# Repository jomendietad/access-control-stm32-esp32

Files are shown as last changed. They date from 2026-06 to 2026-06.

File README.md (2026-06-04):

# Sistema de Control de Acceso Distribuido (STM32 + ESP32-S3)

Este repositorio contiene el código fuente para un **Sistema de Control de Acceso Distribuido**. El proyecto resuelve la necesidad de validar ingresos físicos mediante autenticación de doble factor (RFID local y Visión Artificial remota), dividiendo las responsabilidades computacionales y de control físico entre dos microcontroladores distintos.

Esta arquitectura de "doble nodo" permite aislar y proteger la interacción física en tiempo real, delegando las tareas de procesamiento intensivo, almacenamiento de datos y conectividad web a un nodo especializado.

---

## Filosofía de Diseño: Arquitectura de Nodos

El sistema abandona el paradigma monolítico clásico para operar bajo una topología de **Nodo de Borde (Edge Node)** y **Nodo Central (Core Node)**.

### 1. Nodo Físico / Edge Node (STM32)

Su prioridad absoluta es garantizar la seguridad física y proporcionar una respuesta determinista en tiempo real.

* **Responsabilidades:** Gestión del lector de tarjetas RFID (MFRC522), lectura del sensor de presencia volumétrica (PIR), control de la interfaz visual de usuario (OLED SSD1306) y accionamiento de potencia del relé de la cerradura electromecánica.
* **Estado de Hardware:** Implementado transitoriamente en una tarjeta de desarrollo **NUCLEO-L476RG**. La estructura del firmware está diseñada para garantizar una migración directa y transparente hacia la placa definitiva: una **PCB personalizada basada en el microcontrolador STM32F0**.

### 2. Nodo Central / Core Node (ESP32-S3)

Actúa como el motor computacional del sistema. Gestiona tareas asíncronas de alta carga que comprometerían el tiempo de respuesta del nodo STM32.

* **Responsabilidades:** Procesamiento de algoritmos de visión artificial, gestión de conectividad inalámbrica, alojamiento del servidor HTTP/WebSockets y registro persistente de eventos en memoria no volátil.
* **Nota sobre Retroalimentación Visual (LEDs):** Aunque la capa BSP del ESP32 incorpora el controlador para tiras LED direccionables WS2812 (`bsp_led`), **esta funcionalidad se encuentra inactiva en el flujo principal (`main`) y en la máquina de estados actual**. Las notificaciones visuales del sistema operan exclusivamente a través de la pantalla OLED del STM32.

---

## Diagrama de Bloques del Sistema

El siguiente diagrama ilustra la separación de recursos de hardware y el puente de comunicación asíncrona entre ambas arquitecturas:

```mermaid
graph TD
    %% --- NODO FISICO: STM32 ---
    subgraph STM32 ["EDGE NODE: STM32 (Control Físico)"]
        direction TB
        
        subgraph SwSTM ["Capa de Software (Firmware)"]
            M_STM["Capa Main<br><i>(main.c / App_Task)</i>"]
            A_STM["Capa App: FSM Local<br><i>(app_core.c)</i>"]
            B_STM["Capa BSP: Drivers Placa<br><i>(bsp_placa.h)</i>"]
            
            M_STM --> A_STM
            A_STM <--> B_STM
        end

        %% Periféricos Físicos
        RFID["Lector RFID<br><b>(MFRC522)</b>"]
        PIR["Sensor Presencia<br><b>(PIR)</b>"]
        RELE["Cerradura<br><b>(Relé Potencia)</b>"]
        OLED["Interfaz Usuario<br><b>(OLED SSD1306)</b>"]

        %% Conexiones de Hardware Internas
        B_STM <-->|Bus SPI| RFID
        PIR -->|GPIO Input| B_STM
        B_STM -->|GPIO Output| RELE
        B_STM -->|Bus I2C| OLED
    end

    %% --- NODO COMPUTACIONAL: ESP32-S3 ---
    subgraph ESP32 ["CORE NODE: ESP32-S3 (Procesamiento)"]
        direction TB
        
        subgraph SwESP ["Capa de Software (Infraestructura)"]
            M_ESP["Capa Main<br><i>(main.c)</i>"]
            A_ESP["Capa App: Visión/Lógica<br><i>(app_cv.c)</i>"]
            B_ESP["Capa BSP: Drivers Placa<br><i>(bsp_placa.h)</i>"]
            
            M_ESP --> A_ESP
            A_ESP <--> B_ESP
        end

        %% Periféricos / Conectividad
        RED(("Red Local / Web<br><b>(HTTP / WebSockets)</b>"))
        MEM["Memoria Flash<br><b>(NVS)</b>"]
        LED["Feedback Visual<br><b>(WS2812 RGB)</b>"]

        %% Conexiones de Hardware Internas
        B_ESP <-->|Wi-Fi / TCP-IP| RED
        B_ESP <-->|Bus Interno| MEM
        B_ESP -.->|Driver Inactivo| LED
    end

    %% --- BUS DE COMUNICACIÓN INTER-NODO ---
    B_STM <-->|Canal UART Asíncrono<br>RX / TX Directo| B_ESP

    %% --- ESTILOS VISUALES (Clases CSS para Escaneabilidad) ---
    classDef mainLayer fill:#e3f2fd,stroke:#1565c0,stroke-width:2px,color:#0d47a1;
    classDef appLayer fill:#fff3e0,stroke:#ef6c00,stroke-width:2px,color:#e65100;
    classDef bspLayer fill:#e8f5e9,stroke:#2e7d32,stroke-width:2px,color:#1b5e20;
    classDef hw fill:#f5f5f5,stroke:#424242,stroke-width:1px,color:#212121;
    classDef inactive fill:#fafafa,stroke:#b0bec5,stroke-width:1px,color:#90a4ae,stroke-dasharray: 5 5;

    %% Asignación de Estilos
    class M_STM,M_ESP mainLayer;
    class A_STM,A_ESP appLayer;
    class B_STM,B_ESP bspLayer;
    class RFID,PIR,RELE,OLED,RED,MEM hw;
    class LED inactive;

```

---

## Arquitectura de Software (Strict 3-Layer Architecture)

Para facilitar la inminente migración de hardware (de Nucleo a la PCB personalizada) sin necesidad de refactorizar la lógica central, **ambos microcontroladores** implementan de forma rigurosa una arquitectura de software de tres capas. La totalidad del código fuente está redactada en inglés.

1. **Capa BSP (Board Support Package):** Modularizada por componente físico (ej. `bsp_uart.c`, `bsp_rfid.c`). Es la **única capa autorizada** para interactuar con las bibliotecas del fabricante (HAL de STM32 o ESP-IDF) y manipular registros físicos. Todos los submódulos convergen en un archivo maestro `bsp_placa.h`.
2. **Capa App (Business Logic):** Modularizada por funcionalidad (ej. `app_core.c`, `app_cv.c`). Es completamente agnóstica al hardware; está **estrictamente prohibida** la inclusión de directivas de registros o manejo de periféricos a este nivel. Contiene las máquinas de estado y expone sus interfaces a través de `app.h`.
3. **Capa Main:** Diseñada con un enfoque minimalista. Únicamente incluye `app.h`, ejecuta la inicialización global (`App_Init()`) y mantiene un bucle infinito dedicado de forma exclusiva a la invocación de `App_Task()`.

---

## Flujo de Ejecución y Casos de Uso

El núcleo operativo del sistema reside en la Máquina de Estados Finitos (FSM) ejecutada en la capa de aplicación del STM32 (`app_core.c`). Este bucle principal (`App_Task`) opera de manera estrictamente asíncrona, evitando bloqueos por funciones de retardo.

### Estado Inicial: `STATE_IDLE`

Representa el estado de reposo y vigilancia. El relé permanece desenergizado (cerradura bloqueada). La pantalla OLED se limpia o muestra un mensaje de espera. En cada iteración del bucle, el STM32 ejecuta tres acciones:

1. Interroga el bus SPI para detectar la presencia de una tarjeta en el lector RFID.
2. Verifica si la rutina de interrupción UART ha señalado la recepción de un comando desde el ESP32.
3. Evalúa el estado lógico del pin asociado al sensor PIR.

A partir de este estado de vigilancia, pueden desencadenarse tres eventos principales:

### Caso 1: Ingreso Concedido por RFID (Validación Local)

1. El usuario aproxima un transpondedor RFID al lector.
2. La capa BSP extrae el UID de la tarjeta y lo transfiere a la capa App.
3. La capa App compara el UID contra la base de datos almacenada localmente.
4. **Al verificar una coincidencia**, la FSM transiciona a `STATE_ACCESS_GRANTED`.
5. Se comanda al BSP para energizar el relé y liberar la cerradura. El display OLED indica **"ACCESS GRANTED"**.
6. Se captura la marca de tiempo actual (`BSP_GetTicks()`). Una vez expirado el intervalo de apertura preconfigurado (ej. 3000 ms), el sistema revierte automáticamente a `STATE_IDLE`.

### Caso 2: Ingreso Concedido por Visión Artificial (Validación Remota + Físico)

1. El ESP32-S3 captura y procesa continuamente secuencias de video buscando identificar un rostro válido.
2. Tras identificar positivamente a un usuario autorizado, el ESP32 transmite un byte de confirmación vía UART: `'K'` (*Known*).
3. La interfaz UART del STM32 recibe el byte asíncronamente y activa una bandera de validación.
4. En el siguiente ciclo de `STATE_IDLE`, la capa App detecta esta bandera y ejecuta la comprobación de **Seguridad de Factor Físico**:
* *¿Se recibió la validación `'K'` y, simultáneamente, el sensor PIR registra nivel ALTO (confirmando la presencia física frente a la puerta)?*

5. Si ambas condiciones se cumplen (mitigando vulnerabilidades por suplantación fotográfica), la FSM transiciona a `STATE_ACCESS_GRANTED` y procede con la rutina de apertura.

### Caso 3: Ingreso Denegado

Este escenario se activa bajo dos premisas:

* **Rechazo Local:** Se detecta una tarjeta RFID, pero su UID no existe en los registros locales.
* **Rechazo Remoto:** El ESP32 procesa un rostro no autorizado y transmite el byte `'U'` (*Unknown*).
* **Flujo Operativo:** La FSM transiciona a `STATE_ACCESS_DENIED`. El relé conserva su estado inactivo (seguridad en modo a prueba de fallos). El display OLED muestra **"ACCESS DENIED"** durante un periodo de penalización, tras el cual la pantalla se limpia y el sistema retorna a `STATE_IDLE`.

```mermaid
flowchart TD
    Start([Bucle Continuo: App_Task]) --> CheckState{"¿Cuál es el<br>Estado Actual?"}
    
    %% ==========================================
    %% --- SECCIÓN: STATE_IDLE ---
    %% ==========================================
    CheckState -->|STATE_IDLE| Poll["Sondear Capa BSP<br><i>(MFRC522, UART, PIR)</i>"]
    Poll --> CondRFID{"¿Tarjeta RFID<br>detectada?"}
    
    %% Rama de Validación RFID
    CondRFID -->|Sí| CheckUID{"¿UID registrado<br>en código?"}
    CheckUID -->|Sí| LockG["Cambiar Estado a:<br><b>STATE_ACCESS_GRANTED</b><br>Guardar t_actual (Ticks)"]
    CheckUID -->|No| LockD["Cambiar Estado a:<br><b>STATE_ACCESS_DENIED</b><br>Guardar t_actual (Ticks)"]
    
    %% Rama de Validación UART + PIR (Se alinea a la izquierda para evitar cruces)
    CondRFID -->|No| CondK{"¿Llegó comando 'K'<br><i>(Rostro Conocido)</i>?"}
    CondK -->|Sí| CheckPIR{"¿Sensor PIR == ALTO?<br><i>(Filtro Anti-Spoofing)</i>"}
    CheckPIR -->|Sí| LockG
    CheckPIR -->|No| ClearK["Limpiar Flag UART<br><i>(Ignorar por seguridad)</i>"] --> End
    
    %% Rama de Rostro Desconocido (Se alinea a la derecha)
    CondK -->|No| CondU{"¿Llegó comando 'U'<br><i>(Desconocido)</i>?"}
    CondU -->|Sí| LockD
    CondU -->|No| End

    %% ==========================================
    %% --- SECCIÓN: STATE_ACCESS_GRANTED ---
    %% ==========================================
    CheckState -->|STATE_ACCESS_GRANTED| ExecG["Acción de Apertura"]
    ExecG --> ActG1["BSP_Relay(ON)<br>OLED = 'ACCESS GRANTED'"]
    ActG1 --> TimeG{"¿Transcurrieron<br>3000 ms?<br><i>(Ticks - t_actual)</i>"}
    
    %% Bucle de retención de tiempo
    TimeG -->|No| ActG1
    TimeG -->|Sí| ResetG["BSP_Relay(OFF)<br>Limpiar Banderas UART<br>Cambiar Estado a: <b>STATE_IDLE</b>"] --> End

    %% ==========================================
    %% --- SECCIÓN: STATE_ACCESS_DENIED ---
    %% ==========================================
    CheckState -->|STATE_ACCESS_DENIED| ExecD["Acción de Rechazo"]
    ExecD --> ActD1["BSP_Relay(OFF)<br>OLED = 'ACCESS DENIED'"]
    ActD1 --> TimeD{"¿Expiró tiempo<br>de penalización?"}
    
    %% Bucle de retención de tiempo
    TimeD -->|No| ActD1
    TimeD -->|Sí| ResetD["Limpiar Pantalla OLED<br>Limpiar Banderas UART<br>Cambiar Estado a: <b>STATE_IDLE</b>"] --> End

    %% Nodo de salida
    LockG --> End
    LockD --> End
    End([Fin de la Iteración])

    %% ==========================================
    %% --- ESTILOS VISUALES (Clases CSS) ---
    %% ==========================================
    classDef stateNode fill:#e3f2fd,stroke:#1565c0,stroke-width:2px,color:#0d47a1;
    classDef decision fill:#fff3e0,stroke:#ef6c00,stroke-width:2px,color:#e65100;
    classDef granted fill:#e8f5e9,stroke:#2e7d32,stroke-width:2px,color:#1b5e20;
    classDef denied fill:#ffebee,stroke:#c62828,stroke-width:2px,color:#b71c1c;
    classDef normal fill:#f5f5f5,stroke:#424242,stroke-width:1px,color:#212121;

    %% Asignación de Estilos
    class Start,End,CheckState,StateIdle stateNode;
    class CondRFID,CheckUID,CondK,CheckPIR,CondU,TimeG,TimeD decision;
    class LockG,ExecG,ActG1,ResetG granted;
    class LockD,ExecD,ActD1,ResetD denied;
    class Poll,ClearK normal;

```

---

## Estructura del Repositorio

El repositorio separa de forma lógica y física los entornos de desarrollo para prevenir conflictos entre dependencias, agilizar el proceso de compilación y centralizar la documentación de hardware.

```text
/
├── PCB-Design/                        # Archivos de hardware y manufactura de la PCB custom
│   ├── Altium/                        # Archivos fuente de Altium Designer (esquemáticos, PCB layout)
│   └── gerbers.zip                    # Archivos Gerber listos para fabricación (basada en STM32F0)
│
├── esp32-s3-control-access-final/     # Firmware del ESP32-S3
│   ├── main/                          # Código fuente (App, BSP, Main)
│   ├── CMakeLists.txt                 # Sistema de construcción de ESP-IDF
│   └── partitions.csv                 # Mapa de particiones NVS y de la aplicación
│
├── stm32-nucleo-l476rg-control-access/# Firmware del STM32
│   ├── src/                           # Código fuente (App, BSP, Main)
│   ├── platformio.ini                 # Configuración de entorno y especificación de hardware
│   └── README.md                      # Documentación para la migración a STM32F0
│
└── proyecto.code-workspace            # Espacio de trabajo integrado para Visual Studio Code

```

## Herramientas de Desarrollo

* **Entorno STM32:** El desarrollo, compilación y despliegue se administran a través del ecosistema **PlatformIO**.
* **Entorno ESP32-S3:** El desarrollo se rige estrictamente por la **extensión oficial de ESP-IDF** para VS Code, empleando CMake como sistema de construcción nativo.
* **Diseño de Hardware:** La captura esquemática y el diseño de la placa de circuito impreso (PCB) se realizan en **Altium Designer**, generando los archivos estandarizados Gerber para la manufactura física.

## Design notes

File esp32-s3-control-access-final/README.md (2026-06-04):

# Firmware del Nodo de Conectividad y Procesamiento Avanzado (ESP32-S3) - Control de Acceso

Este directorio contiene el código fuente del firmware para el microcontrolador **ESP32-S3**, el cual actúa como el **Nodo Central de Conectividad y Procesamiento Avanzado (Core Node)** dentro del sistema distribuido de control de acceso. Su propósito principal es gestionar las tareas de alta carga lógica: administración de la pila de red (Wi-Fi), despliegue de servicios web integrados (servidor HTTP y WebSockets), procesamiento de algoritmos de visión artificial (`app_cv`) y el almacenamiento de registros en la memoria Flash no volátil.

Adicionalmente, el firmware incluye la base para el control de retroalimentación lumínica mediante tiras LED direccionables (WS2812), aunque **esta funcionalidad se encuentra inactiva en la lógica principal de la versión actual**.

Este nodo envía de manera asíncrona las solicitudes de hardware enviadas por el nodo periférico (STM32) mediante UART, evalúa el veredicto de acceso y notifica el resultado para autorizar o denegar la apertura física de la cerradura.

---

## Arquitectura de Software (Strict 3-Layer Architecture)

El firmware implementa de forma rigurosa una **Arquitectura Modular de 3 Capas**, aislando completamente la lógica de negocio de las APIs nativas del framework de Espressif (ESP-IDF) y de FreeRTOS. Todo el código fuente (funciones, variables, estructuras y comentarios) está redactado en inglés.

### 1. Main Layer (`main/main.c`)

Es el punto de entrada principal del chip (`app_main`). Su estructura es minimalista; se limita a incluir la cabecera maestra de la aplicación (`app.h`), invocar la función de inicialización del núcleo (`App_Init()`) e ingresar al bucle infinito ejecutando de forma cíclica y no bloqueante la tarea principal (`App_Task()`).

```c
#include "app.h"

void app_main(void) {
    App_Init();
    while (1) {
        App_Task();
    }
}

```

### 2. App Layer (`main/app/`)

Contiene las reglas de negocio, los algoritmos de toma de decisiones y el procesamiento de datos biométricos. **Se prohíbe estrictamente la inclusión de cabeceras nativas del SDK (como `esp_wifi.h`, `driver/gpio.h`, etc.) o llamadas directas a FreeRTOS.** Toda interacción con el hardware se canaliza mediante las abstracciones del BSP.

* **`app.h`:** Cabecera unificada de la capa de aplicación. Es el único enlace visible para el archivo `main.c`.
* **`app_core.c` / `.h`:** Coordina la Máquina de Estados Finitos (FSM) del sistema central. Procesa las tramas UART recibidas del STM32, solicita la validación facial al módulo de visión y determina si el acceso debe ser concedido. *(Nota: Aunque posee la estructura para coordinar efectos visuales, las llamadas hacia el driver de los LEDs no están implementadas en el flujo actual).*
* **`app_cv.c` / `.h`:** Submódulo encargado del procesamiento de imágenes y visión artificial. Para adaptarse a las limitaciones del microcontrolador, emplea un enfoque algorítmico tradicional, ultraligero y de bajo costo computacional:
1. **Detección Facial:** Utiliza segmentación por umbrales de color de piel (*Skin Color Thresholding*). Escanea el búfer de imagen buscando píxeles en el espacio RGB que cumplan reglas heurísticas estrictas para trazar una caja delimitadora alrededor del sujeto.
2. **Reconocimiento Facial:** Extrae características de la imagen recortada comprimiendo la región a una cuadrícula de 10x10 píxeles en una escala de grises aproximada (*Template Matching*).
3. **Inferencia:** Compara la cuadrícula de captura actual con la plantilla almacenada del usuario registrado evaluando el margen de error a través de la Suma de Diferencias al Cuadrado (SSD):

$$SSD = \sum_{i=0}^{99} (PixelActual_i - PixelPlantilla_i)^2$$

Si la diferencia es inferior al umbral predefinido, el sistema emite un veredicto de coincidencia exitosa (`'K'` - *Known*); de lo contrario, lo rechaza (`'U'` - *Unknown*).

### 3. BSP Layer (Board Support Package) (`main/bsp/`)

Es la capa de abstracción de hardware de bajo nivel. **Es la única sección del firmware autorizada para realizar llamadas a las funciones de ESP-IDF y operar primitivas de FreeRTOS.** Se encuentra modularizada por servicios físicos:

* **`bsp_placa.c` / `.h`:** Inicializa los componentes esenciales, coordina el orden de arranque de los subsistemas y expone la base de tiempo en milisegundos (`BSP_GetTicks()`).
* **`bsp_os.c` / `.h`:** Encapsula las funciones de FreeRTOS (creación de tareas, colas de mensajes y semáforos), evitando que la capa de aplicación dependa de tipos de datos nativos como `TaskHandle_t`.
* **`bsp_wifi.c` / `.h`:** Configura el periférico de radio, inicializa la pila TCP/IP de lwIP y gestiona el ciclo de vida de la conexión Wi-Fi en modo Estación (STA), incluyendo rutinas de reconexión automática.
* **`bsp_uart.c` / `.h`:** Configura el periférico UART interno para el enlace serie con el STM32. Utiliza interrupciones y buffers circulares para una recepción asíncrona no bloqueante (recepción implementada solo para una prueba de funcionamiento del UART en loopback).
* **`bsp_led.c` / `.h`:** Driver desarrollado para el control de la tira LED WS2812 mediante el periférico RMT o SPI. *Aclaración: El driver se encuentra programado y disponible a nivel de hardware, pero sus rutinas no son invocadas actualmente por la lógica principal de la aplicación.*
* **`bsp_storage.c` / `.h`:** Abstrae el almacenamiento en la memoria flash interna utilizando NVS (Non-Volatile Storage) o sistemas de archivos (SPIFFS/FAT) para la persistencia de configuraciones.
* **`bsp_tcp.c` / `.h` y `bsp_web.c` / `.h`:** Implementan la capa de sockets y el servidor web local. Exponen los endpoints HTTP y el canal de WebSockets para la transmisión en tiempo real de telemetría y video fluido (*streaming*) hacia un panel de control externo.

---

## Configuración de Periféricos y Recursos del Sistema

| Recurso / Periférico | Función en el Sistema | Configuración de Software (ESP-IDF) |
| --- | --- | --- |
| **UART Connection** | Enlace serie bidireccional con STM32 | Puerto `UART_NUM_1` (Pines TX/RX según ruteado) |
| **WS2812 LED Strip** | Driver lumínico | Periférico `RMT` / Driver `led_strip` *(Inactivo en App)* |
| **Wi-Fi Radio** | Conectividad a la red local | Modo `WIFI_MODE_STA` con DHCP activo |
| **NVS Flash** | Almacenamiento no volátil | Partición `nvs` por defecto en la tabla de memoria |
| **HTTP/WS Server** | API de control y WebSockets | Servidor asíncrono en puerto `80` |

El particionado de la memoria flash externa se encuentra definido explícitamente en el archivo `partitions.csv` ubicado en la raíz del proyecto, con el fin de optimizar el espacio asignado al almacenamiento y a las operaciones de visión artificial.

---

## Entorno de Desarrollo y Flujo de Trabajo (ESP-IDF Nativo)

A diferencia del nodo STM32 (gestionado por PlatformIO), el desarrollo y compilación de este firmware se realiza de manera exclusiva a través del framework **ESP-IDF nativo de Espressif**, utilizando el sistema de construcción **CMake** e integrado en **Visual Studio Code**.

### Requisitos e Instalación

1. Disponer de un entorno operativo compatible con herramientas de compilación de GNU (Toolchains).
2. Instalación de **Visual Studio Code**.
3. Instalación de la extensión **ESP-IDF Extension** oficial desde el marketplace.
4. Ejecutar el asistente de la extensión para descargar la versión estable del SDK de ESP-IDF, que incluye herramientas vitales como el compilador `xtensa-esp32s3-elf-gcc`, `cmake` y `ninja`.

### Configuración Inicial de Credenciales

Por directrices de seguridad, las credenciales de la red Wi-Fi no están incluidas en el repositorio. Es obligatorio configurarlas antes de iniciar el proceso de compilación:

1. Localice el archivo de plantilla `main/secrets.example.h`.
2. Genere una copia en el mismo directorio y renómbrela estrictamente como `secrets.h`.
3. Edite las macros en `main/secrets.h` con los parámetros de su red local:

```c
#define WIFI_SSID     "Tu_Nombre_De_Red"
#define WIFI_PASSWORD "Tu_Contraseña_Segura"

```

### Flujo de Compilación y Grabación desde VS Code

Abra la carpeta `esp32-s3-control-access-final/` en su editor. La extensión ESP-IDF detectará automáticamente el archivo `CMakeLists.txt`. El ciclo de desarrollo se controla mediante la barra de acciones inferior o la paleta de comandos:

* **Set Device Target:** Seleccione el microcontrolador `esp32s3` y la configuración base (`sdkconfig`).
* **Build:** Ejecuta la cadena de compilación de todo el firmware, generando los archivos binarios en el directorio `build/`.
* **Flash:** Conecte la placa ESP32-S3 vía USB. Seleccione el modo de grabación (UART o JTAG USB nativo) y el puerto correspondiente para transferir el firmware a la memoria flash.
* **Monitor:** Inicia la terminal serie de Espressif (configurada por defecto a 115200 baudios) para visualizar los registros de arranque del bootloader, las trazas del proceso de conexión Wi-Fi y la depuración del sistema.

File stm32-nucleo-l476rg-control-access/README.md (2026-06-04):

# Firmware del Nodo Local (STM32) - Control de Acceso

Este directorio contiene el código fuente del firmware para el microcontrolador STM32, el cual funciona como el **Nodo de Borde (Edge Node)** dentro del sistema distribuido de control de acceso. Su función principal es gestionar las interfaces físicas de entrada/salida en tiempo real, capturar las credenciales de las tarjetas RFID, evaluar la presencia de usuarios mediante un sensor PIR, operar el actuador de la cerradura electromecánica y proporcionar retroalimentación visual inmediata a través de una pantalla OLED.

Toda la lógica de validación remota y la conectividad avanzada se delegan al nodo central (ESP32-S3), con el cual este nodo se comunica de manera asíncrona.

> **NOTA DE MIGRACIÓN DE HARDWARE:** La implementación actual está configurada y validada para la tarjeta de desarrollo **NUCLEO-L476RG**. No obstante, la estructura del firmware ha sido diseñada bajo una arquitectura estrictamente desacoplada para permitir una migración directa a una PCB personalizada basada en el microcontrolador **STM32F0**. Los detalles técnicos para llevar a cabo esta transición se describen en la sección final de este documento.

---

## Arquitectura de Software (Strict 3-Layer Architecture)

El firmware se ha desarrollado siguiendo de forma rigurosa una **Arquitectura Modular de 3 Capas**, lo que garantiza que la lógica de negocio permanezca completamente aislada de los cambios de hardware o de fabricante. Todo el código fuente, incluyendo funciones, variables y comentarios, está redactado en inglés.

### 1. Main Layer (`src/main.c`)

Es el punto de entrada del programa. Se mantiene minimalista y libre de código de inicialización directa de periféricos. Su único propósito es incluir el archivo maestro de la aplicación (`app.h`), invocar la función de inicialización global de la lógica de negocio y mantener el bucle de ejecución principal de forma no bloqueante.

```c
#include "app.h"

int main(void) {
    App_Init();
    while (1) {
        App_Task();
    }
}

```

### 2. App Layer (`src/app/`)

Esta capa contiene la lógica de negocio y las reglas operativas del control de acceso. **Tiene estrictamente prohibido incluir librerías del fabricante (HAL) o archivos de cabecera del hardware.** Toda interacción con el entorno físico se realiza mediante las abstracciones provistas por el BSP.

* **`app.h`:** Cabecera maestra de la aplicación. Es el único archivo que interactúa directamente con `main.c`.
* **`app_core.c` / `.h`:** Implementa la Máquina de Estados Finitos (FSM) del sistema y las reglas de validación temporal utilizando marcas de tiempo no bloqueantes (`BSP_GetTicks()`).

**Máquina de Estados de la Aplicación (FSM)**

El sistema transita de manera cooperativa entre tres estados principales:

* **`STATE_IDLE`:** El sistema se encuentra en reposo. Borra la pantalla OLED, mantiene el relé de la cerradura desactivado, realiza sondeos continuos al lector RFID y verifica las banderas de recepción de la UART y del sensor PIR.
* **`STATE_ACCESS_GRANTED`:** Se activa cuando una credencial es válida (local o remota). Ordena al BSP energizar el relé para abrir la puerta y actualiza el display con el mensaje `"ACCESS GRANTED"`. Inicia un esquema de temporización no bloqueante para retornar automáticamente a `STATE_IDLE` tras 3000 ms.
* **`STATE_ACCESS_DENIED`:** Se activa ante un intento de acceso inválido. Muestra en la pantalla `"ACCESS DENIED"`, bloquea el actuador y regresa al estado `STATE_IDLE` tras un periodo de penalización.

**Reglas de Validación de Acceso**

El sistema concede el acceso si se cumple alguno de los siguientes escenarios mientras se encuentra en `STATE_IDLE`:

* **Validación Local (RFID):** El BSP reporta la lectura de una tarjeta cuyo identificador coincide exactamente con el UID autorizado almacenado localmente en el firmware.
* **Validación Remota Combinada (Visión Artificial + Presencia):** La capa de aplicación detecta que la UART ha recibido el carácter de validación exitosa desde el ESP32 (`'K'` de *Known*) y, de manera simultánea, el BSP confirma detección de movimiento en el sensor PIR. Esto previene falsos positivos por rostros detectados sin un usuario real presente.

### 3. BSP Layer (Board Support Package) (`src/bsp/`)

Representa la capa de abstracción de hardware. **Es la única sección del firmware autorizada para interactuar con la HAL (Hardware Abstraction Layer) de STM32 y manipular registros físicos.** Se encuentra modularizada por componentes físicos:

* **`bsp_placa.c` / `.h`:** Centraliza la inicialización de todos los periféricos, configura los árboles de reloj (Clock Tree) y expone la base de tiempo del sistema en milisegundos (`BSP_GetTicks()`) a través del SysTick.
* **`bsp_gpio.c` / `.h`:** Administra los pines de propósito general. Configura el pin del sensor PIR como entrada digital y el pin del relé de la cerradura como salida digital Push-Pull.
* **`bsp_uart.c` / `.h`:** Configura `USART2` para la salida de depuración (115200 bps) y `USART1` para la comunicación bidireccional con el ESP32-S3. La recepción de datos se maneja estrictamente mediante interrupciones de hardware (RXNE) para evitar bloqueos en la FSM.
* **`bsp_display.c` / `.h`:** Controlador optimizado para la pantalla OLED SSD1306 vía `I2C1`. Utiliza un buffer de video en la memoria RAM y transmite los cambios por el bus I2C de forma masiva, optimizando los tiempos de procesamiento.
* **`bsp_rfid.c` / `.h` y `mfrc522.c` / `.h`:** Implementan el protocolo SPI para la comunicación con el módulo RFID MFRC522 a través de `SPI1`. Gestionan la detección de tarjetas y la extracción del UID. *Nota: El UID autorizado (`0xB6, 0x7B, 0x0C, 0x03`) se encuentra definido temporalmente en este módulo.*

---

## Conexiones de Hardware y Pines (Configuración NUCLEO-L476RG)

| Periférico / Módulo | Señal | Pin STM32 (L476RG) | Configuración de Bus / Tipo |
| --- | --- | --- | --- |
| **MFRC522 (RFID)** | SPI_SCK | `PA5` | Alternate Function (`SPI1`) |
| **MFRC522 (RFID)** | SPI_MISO | `PA6` | Alternate Function (`SPI1`) |
| **MFRC522 (RFID)** | SPI_MOSI | `PA7` | Alternate Function (`SPI1`) |
| **MFRC522 (RFID)** | SPI_CS / NSS | `PB6` | GPIO Output (Software CS) |
| **MFRC522 (RFID)** | HARD_RESET | `PA9` | GPIO Output |
| **SSD1306 (OLED)** | I2C_SCL | `PB8` | Alternate Function (`I2C1`, Open-Drain) |
| **SSD1306 (OLED)** | I2C_SDA | `PB9` | Alternate Function (`I2C1`, Open-Drain) |
| **Sensor PIR** | DIGITAL_OUT | `PA0` | GPIO Input (Floating/Pull-Down) |
| **Relé Cerradura** | CONTROL_GATE | `PA1` | GPIO Output (Push-Pull) |
| **Conexión ESP32** | UART_TX (Hacia ESP) | `PA9` | Alternate Function (`USART1`) |
| **Conexión ESP32** | UART_RX (Desde ESP) | `PA10` | Alternate Function (`USART1`, RX Interrupt) |
| **Depuración PC** | ST-LINK TX | `PA2` | Alternate Function (`USART2`) |
| **Depuración PC** | ST-LINK RX | `PA3` | Alternate Function (`USART2`) |

---

## Flujo de Trabajo y Herramientas de Desarrollo

El desarrollo y compilación del firmware están completamente automatizados mediante **PlatformIO**, eliminando la dependencia de IDEs propietarios.

**Requisitos Previos**

* Instalación de **Visual Studio Code**.
* Instalación de la extensión **PlatformIO IDE**.

**Compilación y Despliegue**
Al abrir el directorio `stm32-nucleo-l476rg-control-access/` en VS Code, PlatformIO gestionará automáticamente las dependencias, herramientas de compilación y el framework STM32Cube HAL.

* **Build:** Compila el código fuente y genera los binarios (ELF/HEX/BIN) en el directorio `.pio/build/`.
* **Upload:** Se conecta a través del ST-LINK integrado (SWD), borra la memoria flash y graba el nuevo firmware.
* **Serial Monitor:** Abre la consola de depuración conectada al `USART2` (115200 baudios) para monitorear los registros del sistema y las transiciones de la FSM.

---

## Hoja de Ruta para la Migración a PCB Personalizada (STM32F0)

La arquitectura por capas asegura que **no se deba modificar el código de la capa `App` ni el archivo `main.c**` durante el proceso de migración. Las adaptaciones se limitan exclusivamente a la reconfiguración de la capa `BSP`. Siga los siguientes pasos:

### Paso 1: Configuración del Entorno (`platformio.ini`)

Abra el archivo `platformio.ini` y reemplace los parámetros de la placa Nucleo por los del chip STM32F0 correspondiente a su hardware:

```ini
[env:genericSTM32F030R8]
platform = ststm32
board = genericSTM32F030R8 ; Sustituir por el número de parte exacto
framework = stm32cube
monitor_speed = 115200

```

### Paso 2: Actualización de las Librerías HAL

En cada archivo de la carpeta `src/bsp/`, reemplace la cabecera de la familia L4 por la correspondiente a la familia F0:

```c
// Cambiar:
#include "stm32l4xx_hal.h"

// Por:
#include "stm32f0xx_hal.h"

```

### Paso 3: Reconfiguración de Pines y Funciones Alternas (AF)

Actualice las asignaciones de hardware basándose en el ruteo de la nueva PCB:

* **Pines de Propósito General (`bsp_gpio.c`):** Ajuste los puertos y pines asignados al sensor PIR y al relé.
* **Buses de Comunicación (`bsp_uart.c`, `bsp_display.c`, `bsp_rfid.c`):** Si los canales periféricos cambiaron (ej. de `SPI1` a `SPI2`), actualice las instancias en el código.
* **Mapeo de Funciones Alternas:** Verifique las macros de función alterna (ej. `GPIO_AFX_USARTX`). La familia STM32F0 emplea un mapa de registros diferente al de la serie L4.

### Paso 4: Ajuste del Árbol de Relojes (`bsp_placa.c`)

La serie STM32F0 no cuenta con el oscilador interno MSI de la serie L4. Localice la función `SystemClock_Config(void)` en `bsp_placa.c` y reescriba las estructuras `RCC_OscInitTypeDef` y `RCC_ClkInitTypeDef` para configurar el sistema utilizando el oscilador interno HSI (48 MHz) o un cristal externo HSE. Se recomienda generar una plantilla base con STM32CubeMX para asegurar la precisión de esta configuración.

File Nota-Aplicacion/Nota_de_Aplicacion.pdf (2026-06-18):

# Nota de Aplicacion: Sistema de Control de Acceso ´ Distribuido con Validacion Dual (Edge & Core) ´

Johan Sebastian Mendieta Dilbert Estudiante de Ingeniería Electronica, Universidad Nacional de Colombia, Sede Manizales ´ Correo institucional: jomendietad@unal.edu.co

Resumen—El presente documento detalla el diseno, arquitectu- ˜ ra de software y desarrollo de hardware de un sistema de control de acceso híbrido. Para resolver las limitaciones de rendimiento y bloqueos de interfaz comunes en sistemas integrados monolíticos, se propone una arquitectura de doble nodo. Un STM32 (Edge Node) gestiona las interfaces físicas de tiempo real (RFID, PIR, OLED, Rele), mientras un ESP32-S3 (Core Node) asume la carga ´ computacional de conectividad Wi-Fi, servidor web y procesa-
miento biometrico de visi ´ | on artificial. Se expone la transici ´ | on de ´
una prueba de concepto basada en hardware comercial hacia el diseno de una PCB personalizada en Altium Designer que integra ˜ un microcontrolador STM32F030C8T6 junto a una etapa de potencia de alta eficiencia. Toda la logica del firmware opera bajo ´ una estricta arquitectura modular de tres capas, garantizando la independencia del hardware.

Index Terms—STM32, ESP32-S3, Control de Acceso, Arquitectura de 3 Capas, PCB, Altium Designer, Vision Artificial. ´

I. INTRODUCCION´

Los sistemas modernos de control de acceso enfrentan un desafío tecnico considerable: la necesidad de proporcionar una ´
respuesta física instantanea a est ´ | ímulos de hardware (como
la lectura de una tarjeta o la deteccion de movimiento) al ´ mismo tiempo que ejecutan tareas asíncronas de alta carga computacional (como reconocimiento facial o transmision de ´ video web). Implementar esto en un unico System-on-Chip ´ (SoC) habitualmente resulta en bloqueos (cuellos de botella) o en la perdida de la naturaleza determinista del sistema. ´
Para solventar esta problematica, se implement ´ | o una topo- ´
logía distribuida que separa las responsabilidades de control físico (Edge) de las responsabilidades logicas y conectivas ´
(Core). Esta nota de aplicacion documenta el dise ´ | no integral de ˜
este sistema, abarcando desde las reglas estrictas de desarrollo del firmware en C, hasta el diseno de la placa de circuito ˜ impreso (PCB) final que acopla ambos subsistemas.

II. ARQUITECTURA DEL SISTEMA DE HARDWARE

El diseno se divide conceptualmente y f ˜ | ísicamente en dos
nodos comunicados asíncronamente mediante un bus UART (Tx/Rx) operando a 115200 baudios.

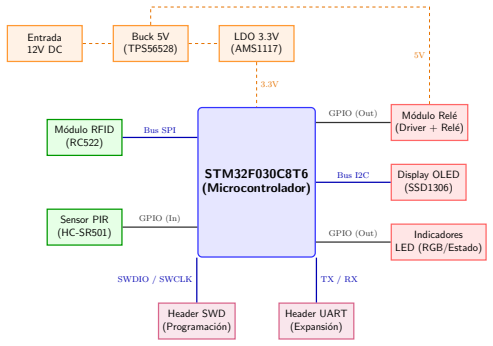
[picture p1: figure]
STM32F030C8T6 (Microcontrolador); LDO 3.3V (AMS1117); Buck 5V (TPS56528); Entrada 12V DC; Módulo RFID (RC522); Sensor PIR (HC-SR501); Módulo Relé (Driver + Relé); Display OLED (SSD1306); Indicadores LED (RGB/Estado); Header SWD (Programación); Header UART (Expansión); Bus SPI; GPIO (In); GPIO (Out); Bus I2C; SWDIO / SWCLK

Figura 1: Diagrama de bloques general de la arquitectura de hardware del sistema. Se ilustra el flujo de señales de datos (SPI, I2C, UART), señales de control (GPIO) y las principales vías de distribución de energía.

1

Figura 1. Diagrama de bloques general del sistema mostrando la division´ entre el Edge Node (STM32) y el Core Node (ESP32-S3).

II-A. Nodo de Borde (Edge Node) - STM32
Este nodo opera bajo restricciones de tiempo real estricto, priorizando la seguridad y la retroalimentacion inmediata del ´ usuario.
Lector RFID (MFRC522): Modulo gen ´ | erico comunica- ´
do por bus SPI, encargado de la validacion primaria de ´ credenciales locales.
Pantalla OLED (SSD1306): Interfaz visual controlada por bus I2C.
Sensor de Presencia (PIR): Conectado a un GPIO
de entrada, actua como verificaci ´ | on de presencia f ´ | ísica

en la puerta (mitigacion de ataques de presentaci ´ | on´
fotografica). ´
Actuador (Rele): ´ Controla el bloqueo electromecanico ´ de la puerta.

II-B. Nodo Central (Core Node) - ESP32-S3
Encargado de tareas de ancho de banda elevado y tiempos de ejecucion variables. ´
Conectividad Wi-Fi y Web: Implementa la pila lwIP en
modo estacion (STA), levantando un servidor as ´ | | íncrono
para el manejo de endpoints HTTP y WebSockets.
Almacenamiento No Volatil (NVS): ´ | Administra creden-
ciales y registros del sistema.
Procesamiento Visual: Ejecuta el algoritmo heurístico
de extraccion y validaci ´ | on de caracter ´ | ísticas faciales.

III. ESTRICTA ARQUITECTURA MODULAR DE SOFTWARE
(3 CAPAS)
El exito de la migraci ´ | on tecnol ´ | ogica, pasando de una tar- ´
jeta de evaluacion Nucleo-L476RG a una PCB personalizada ´ basada en un STM32F0, recae en la implementacion rigurosa ´ de una arquitectura de software de 3 capas. Esta metodología
aísla la logica de negocio de las librer ´ | ías del fabricante (HAL
de STM32 o ESP-IDF).
Tanto en el ecosistema PlatformIO (STM32) como en ESP-
IDF nativo (ESP32), el codigo en ingl ´ | es se estructura de la ´
siguiente manera:
III-1. Capa BSP (Board Support Package): Es la unica ´ capa autorizada para incluir librerías de fabricantes e interactuar directamente con registros físicos de hardware. Todos los
modulos perif ´ | ericos ( ´ | bsp_uart.c, bsp_rfid.c) exponen
su funcionalidad mediante rutinas abstractas encapsuladas finalmente en un archivo maestro bsp_placa.h.
III-2. Capa App (Business Logic): Construida alrededor de la cabecera maestra app.h. Contiene las maquinas de ´ estado finito (FSM) no bloqueantes que rigen el comportamiento del sistema. La inclusion de cabeceras relacionadas ´
con hardware esta estrictamente prohibida en esta secci ´ | on. La ´
FSM principal transiciona entre tres estados principales:

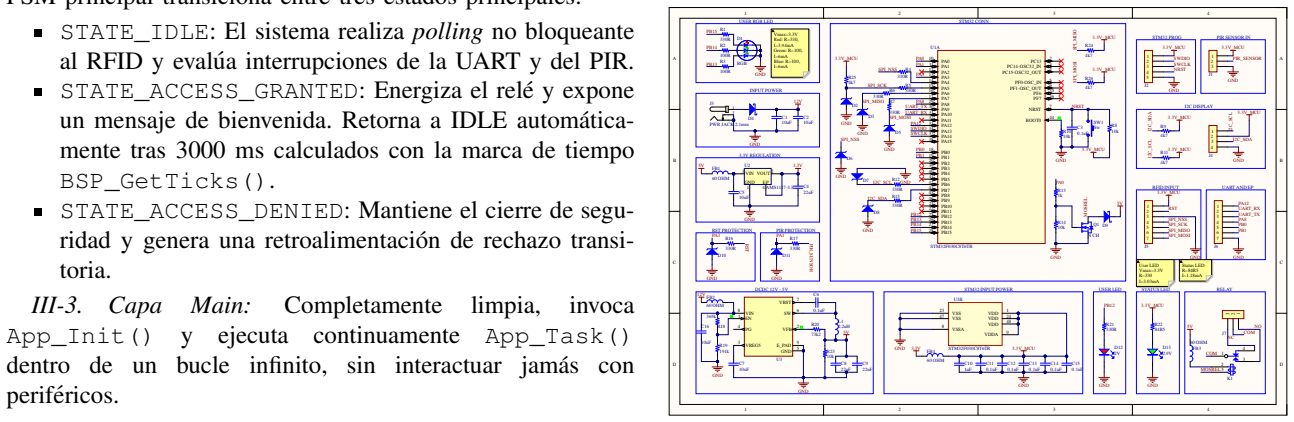
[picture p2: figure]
BSP_GetTicks().; toria.; III-3. Capa; Main:; Completamente; limpia,; invoca; App_Init(); y ejecuta continuamente App_Task(); perifericos. ´; PC14-OSC32_IN; PC15-OSC32_OUT; PF0-OSC_IN; PF1-OSC_OUT; NRST; BOOT0; STM32F030C8T6TR; VSS 23 VSS 47; VSSA 8; VDD; VDDA; PWR JACK 2.1mm; VIN 8 EN 1; VFB 2; VREG5 3; VBST; E_PAD; GND 5; VIN 3; GND 1; VOUT 2; AMS1117-3.3; RGB; GND; 3.3V_MCU; SWDIO; SWDIO SWCLK; SWCLK; INPUT POWER; 3.3V REGULATION; DCDC 12V - 5V; STM32 INPUT POWER; MOSREL; COM; I2C_SCL; R11 I2C_SCL; I2C_SDA; R9 I2C_SDA; STM32 PROG; I2C DISPLAY; PIR SENSOR IN; SPI_SCK; SPI_MISO; SPI_MOSI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

STATE_IDLE: El sistema realiza polling no bloqueante al RFID y evalua interrupciones de la UART y del PIR. ´ STATE_ACCESS_GRANTED: Energiza el rele y expone ´ un mensaje de bienvenida. Retorna a IDLE automatica- ´ mente tras 3000 ms calculados con la marca de tiempo

STATE_ACCESS_DENIED: Mantiene el cierre de seguridad y genera una retroalimentacion de rechazo transi- ´

dentro de un bucle infinito, sin interactuar jamas con ´

IV. PROCESAMIENTO DE VISION´ ARTIFICIAL

Para el reconocimiento facial, en lugar de saturar el ESP32-S3 con modelos vectoriales masivos orientados a la NPU, el modulo ´ app_cv.c emplea un algoritmo heurístico ultraligero y determinista, optimizando el consumo y maximizando los FPS en el microcontrolador.

IV-A. Segmentacion y Bounding Box ´
El fotograma en el bufer es sometido a segmentaci ´ | on´
mediante umbrales de color de piel (Skin Color Thresholding). Se analiza el espacio de color para identificar grupos de píxeles viables que cumplan reglas estrictas, trazando un area ´ delimitadora para el rostro.

IV-B. Template Matching y Suma de Diferencias (SSD)
La region de inter ´ | es extra ´ | ída se comprime espacialmente
a una cuadrícula en escala de grises aproximada de 10 × 10
píxeles. La inferencia matematica compara esta matriz ( ´ | Pixe-
lActual) con la firma almacenada en el sistema (PixelPlantilla) usando la metrica de la Suma de Diferencias al Cuadrado ´ (SSD):

SSD =

X

99

i=0

(P ixelActuali − P ixelPlantillai)

2
(1)

Si el calculo de SSD arroja un valor inferior al umbral ´ de reconocimiento (RECOGNITION_THRESHOLD), el ESP32 transmite el byte ’K’ (Known) al STM32; de lo contrario, envía ’U’ (Unknown). El STM32 somete este veredicto a
una Validacion de Presencia Cruzada ´ | , concediendo el acceso
unicamente si el comando ´ | ’K’ coincide con un flanco activo
del sensor PIR.
V. DISENÕ ELECTRONICO Y ´ | PCB PERSONALIZADA

La prueba de concepto (PoC) inicial demostro la estabilidad ´ de la maquina de estados sobre hardware en protoboard utili- ´
zando componentes prestados. El diseno electr ˜ | onico definitivo ´
traslada esta topología a una PCB a la medida disenada en ˜ Altium Designer.
Figura 2. Extracto del diagrama esquematico dise ´ | nado en Altium, eviden- ˜
ciando las etapas de procesamiento y control de hardware periferico. ´

V-A. Migracion de Unidad Central (Edge) ´
Se incorporo el microcontrolador ´ | STM32F030C8T6 como
nucleo local permanente, en sustituci ´ | on del STM32L4. Se ´
previo la modularidad del nRF54L05, pero para este ciclo, la ´ placa integra el ESP32-S3 a traves de arreglos de conectores ´ (headers).

V-B. Arbol de Potencia y Eficiencia ´

El diseno toma voltaje primario (t ˜ | ípicamente 12V DC para
saturar la bobina del electroiman o cerradura) y lo reduce ´ mediante un regulador Buck de alta eficiencia TPS54329 de Texas Instruments. Para esta etapa de conmutacion se ´ desarrollaron los footprints personalizados garantizando el manejo termico, apoyado por: ´
Inductores de potencia montados en superficie (Pulse Electronics BDCD002520122R2MS1 y Wurth Elektro- ¨ nik 74438356033).
Redes de capacitores multicapa ceramicos (MLCC) de ´ Murata y Samsung (ej. CL31B106KAHNFNE) para el filtrado de rizado a la entrada y salida.

Entrada Jack J3
12V DC

Buck DC-DC
TI TPS56528
12V a 5V (Máx: 5A)

LDO
AMS1117-3.3
5V a 3.3V (Máx: 1A)

Relé + MOSFET
Consumo: ∼75 mA

MCU STM32F030
Consumo: ∼40 mA

Módulo RFID
Consumo: ∼26 mA

Display OLED
Consumo: ∼20 mA

LEDs (RGB + Estado)
Consumo: ∼40 mA

Sensor PIR
Consumo: ∼0.06 mA

12V

5V

5V

3.3V

Figura 1: Arbol de Potencia del Sistema. Representación de las etapas de regu- ´ lación y distribución de corriente máxima estimada para cada carga.

1

Figura 3. Arbol de distribuci ´ | on de potencia mostrando niveles l ´ | ogicos (3.3V) ´
y derivaciones para perifericos actuadores (5V/12V). ´

V-C. Consideraciones de Ruteo en la PCB
El trazo de pistas del proyecto separo estrictamente el ´ dominio ruidoso (conmutacion del regulador TPS54329 y pico ´
inductivo del rele) del dominio l ´ | ogico. Se implementaron ´
polígonos de vertido (GND Planes) ininterrumpidos bajo los buses críticos de comunicacion (SPI para RFID, I2C para ´
OLED) y se garantizo protecci ´ | on transitoria usando un fusible ´
termico rearmable PTC (Bel Fuse 0ZCG0110AF2C). ´
Las interfaces externas se resuelven mediante el jack de entrada de potencia (Same Sky PJ-012B) y bloques de terminales robustos (Altech MBES-152) para la conexion a la cerradura ´ electrica. ´

VI. CONCLUSION´

El desarrollo del Sistema de Control de Acceso Distribuido
demuestra satisfactoriamente como la separaci ´ | on computacio- ´
nal entre Edge y Core previene cuellos de botella críticos en el tiempo de respuesta, garantizando que el reconocimiento visual heurístico por SSD no ralentice las operaciones físicas de seguridad local.
El flujo metodologico implementado permiti ´ | o realizar prue- ´
bas sobre placas comerciales e iterar hacia un esquematico ´ industrial propio sin modificar la capa logica ( ´ App Layer) del firmware en absoluto. A partir del empaquetado final de los archivos de fabricacion (Gerbers), la manufactura de la PCB ´
disenada en Altium consolidar ˜ | a un producto compacto de alto ´
rendimiento biometrico apto para implementaciones en sitio. ´

REFERENCIAS

1. STMicroelectronics, STM32F030x4/x6/x8/xC Datasheet, Rev 6.
2. Texas Instruments, TPS54329 4.5V to 18V Input, 3A Synchronous Step-Down Converter Datasheet.
3. NXP Semiconductors, MFRC522 Standard performance MIFARE and NTAG frontend, Rev 3.9.
4. Espressif Systems, ESP-IDF Programming Guide, API Reference.
5. Altium Limited, Altium Designer Documentation: High-Speed PCB Layout Guidelines.

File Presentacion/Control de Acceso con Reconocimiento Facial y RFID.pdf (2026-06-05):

# Sistema de Control de Acceso con Reconocimiento Facial y RFID

## Desarrollo de Hardware y Software Embebido

### Johan Sebastian Mendieta Dilbert

jomendietad@unal.edu.co

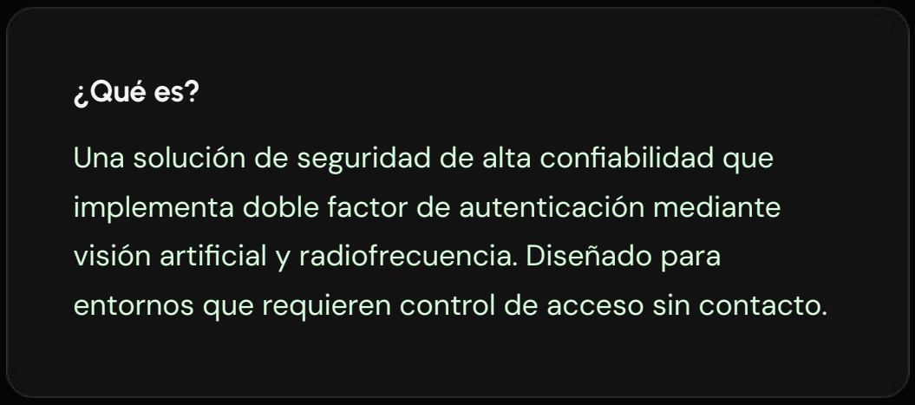
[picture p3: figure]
¿Qué es?

Una solución de seguridad de alta confiabilidad que implementa doble factor de autenticación mediante visión artificial y radiofrecuencia. Diseñado para entornos que requieren control de acceso sin contacto.

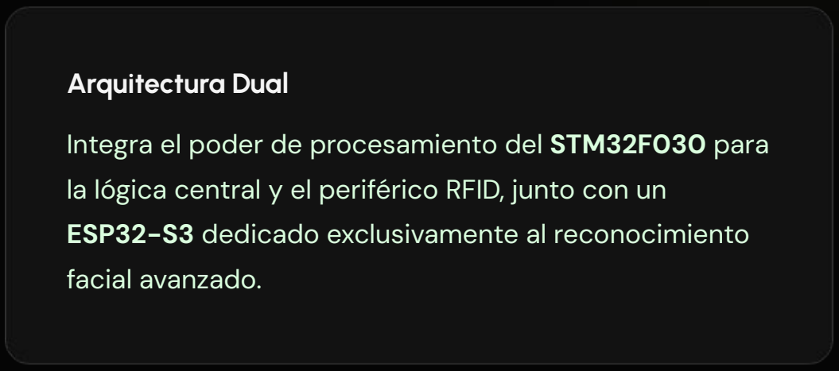
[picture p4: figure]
Arquitectura Dual; facial avanzado.

Integra el poder de procesamiento del STM32F030 para la lógica central y el periférico RFID, junto con un ESP32-S3 dedicado exclusivamente al reconocimiento

# Visión General del Proyecto

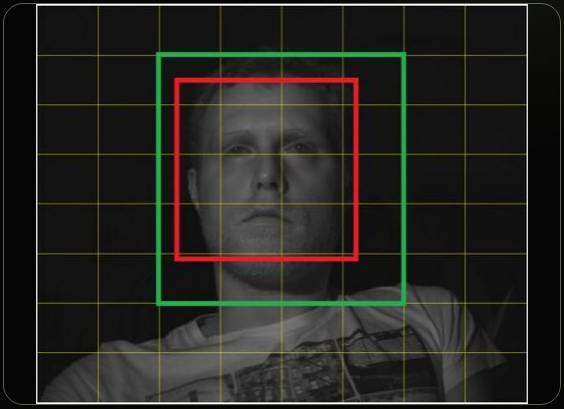
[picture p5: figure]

Detección Facial: Segmentación por umbrales de color de piel (Skin Color Thresholding) procesando el búfer RGB en tiempo real.

Reconocimiento: Extracción de características comprimiendo la región a una cuadrícula de 10x10 píxeles en escala de grises.

Inferencia: Evaluación del margen de error mediante la Suma de Diferencias al Cuadrado (SSD).

# Motor de Visión Artificial

# Arquitectura de Hardware

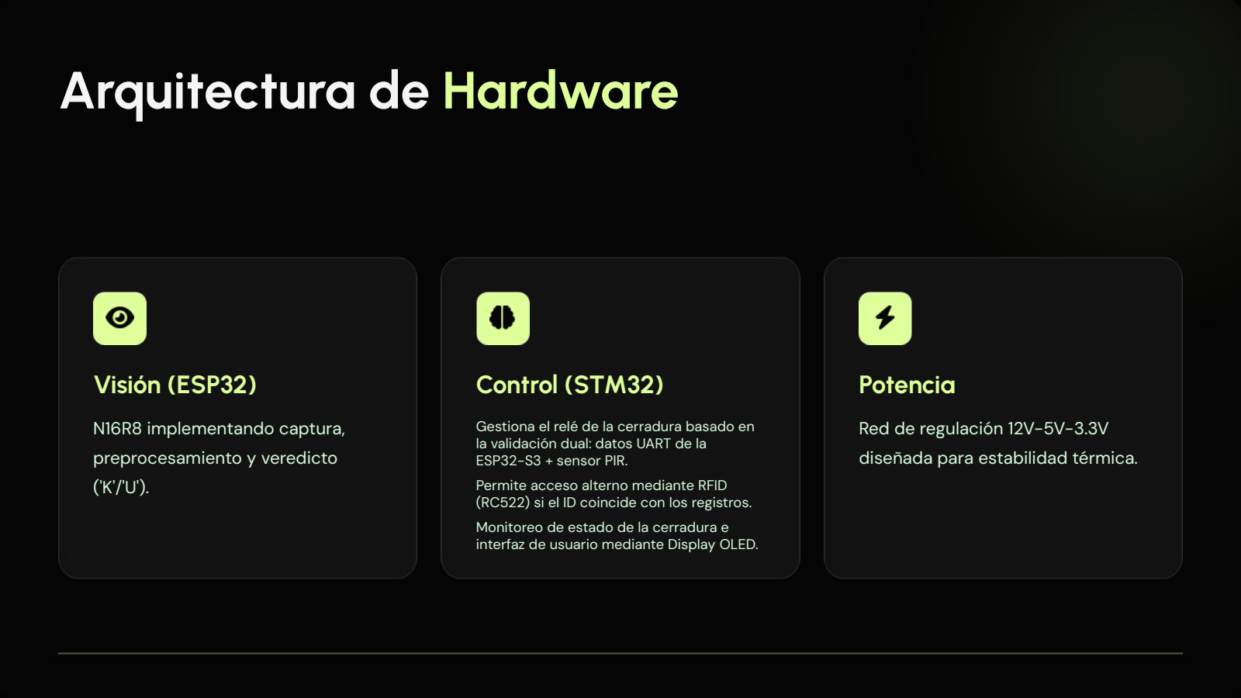
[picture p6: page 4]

## Visión (ESP32)

N16R8 implementando captura, preprocesamiento y veredicto ('K'/'U').

## Potencia

Red de regulación 12V-5V-3.3V diseñada para estabilidad térmica.

## Control (STM32)

Gestiona el relé de la cerradura basado en la validación dual: datos UART de la ESP32-S3 + sensor PIR.
Permite acceso alterno mediante RFID (RC522) si el ID coincide con los registros. Monitoreo de estado de la cerradura e interfaz de usuario mediante Display OLED.

# Arquitectura de Hardware

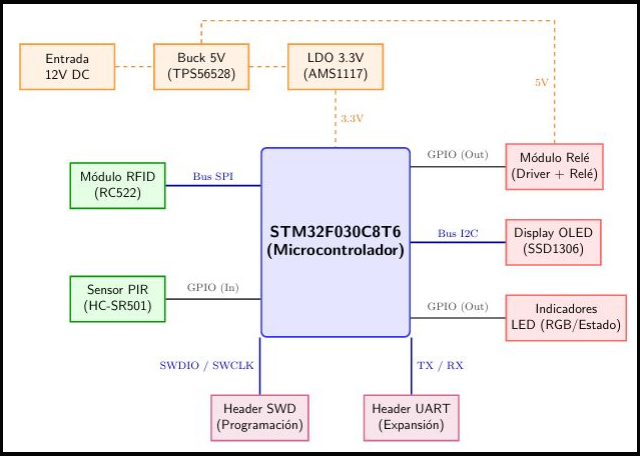
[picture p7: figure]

## CAPACIDAD NODO 5V

5A

Entrada: 12V DC vía Power Jack J3.

Regulación Primaria: Buck TPS56528 (5V) para Relé y sensores.

Regulación Secundaria: LDO AMS1117 (3.3V) para Lógica y RFID.

# Gestión de Energía

# Gestión de Energía

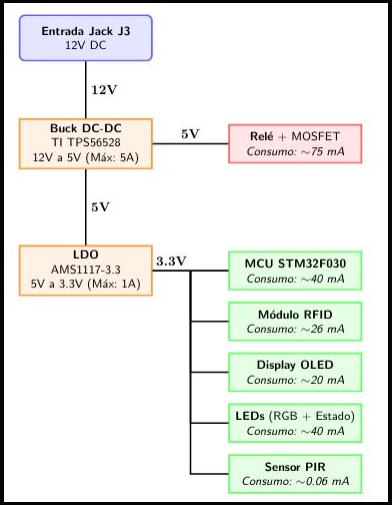
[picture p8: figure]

# Análisis Térmico Calculado

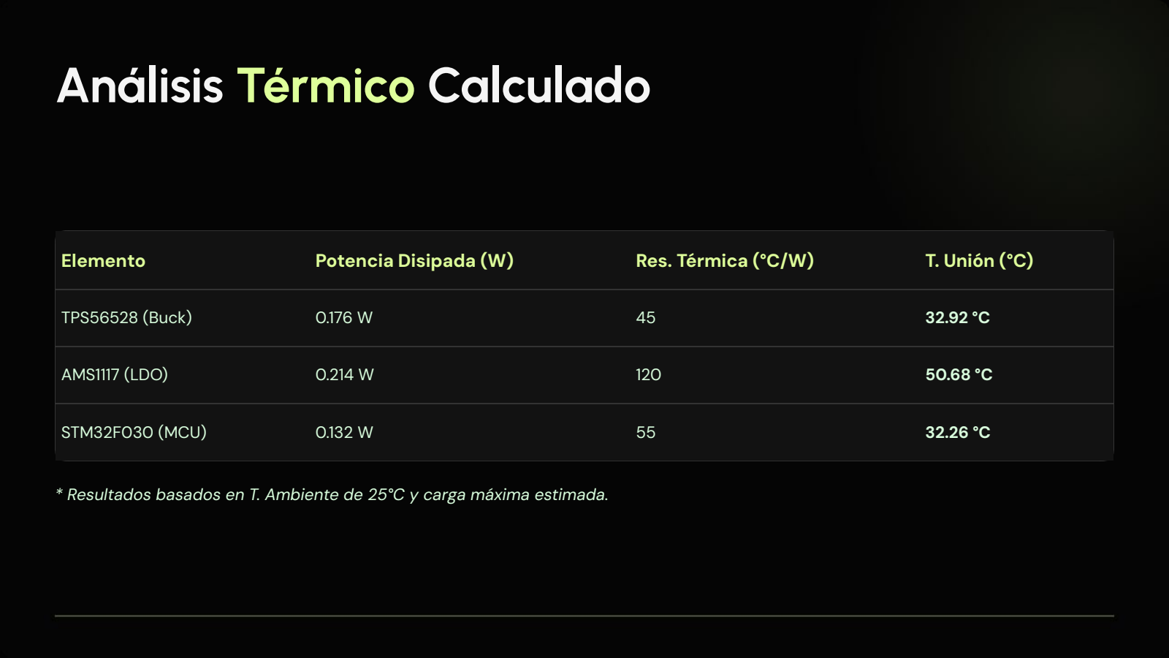
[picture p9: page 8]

* Resultados basados en T. Ambiente de 25°C y carga máxima estimada.

Elemento | Potencia Disipada (W) | Res. Térmica (°C/W) | T. Unión (°C)
TPS56528 (Buck) | 0.176 W | 45 | 32.92 °C
AMS1117 (LDO) | 0.214 W | 120 | 50.68 °C
STM32F030 (MCU) | 0.132 W | 55 | 32.26 °C

# Análisis Térmico Calculado

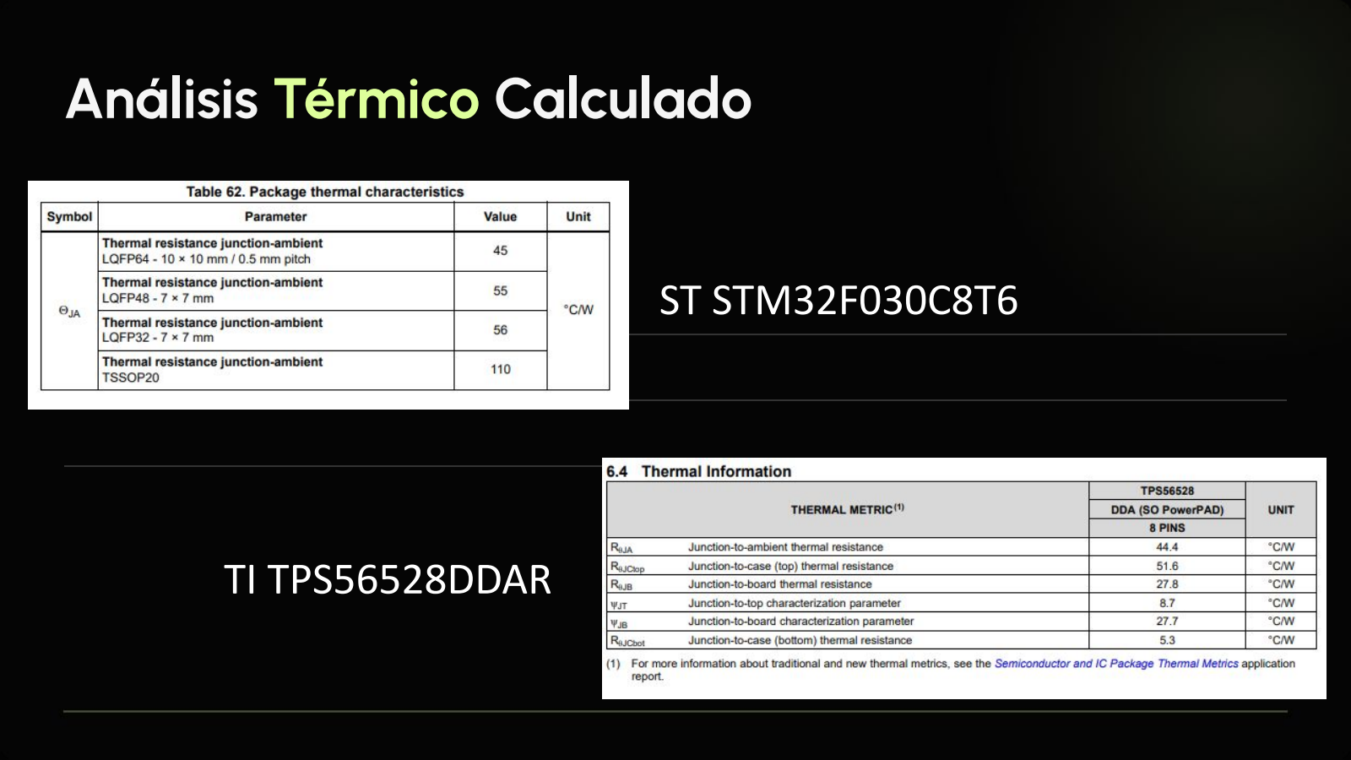
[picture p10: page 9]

# ST STM32F030C8T6

# TI TPS56528DDAR

# Análisis Térmico Calculado

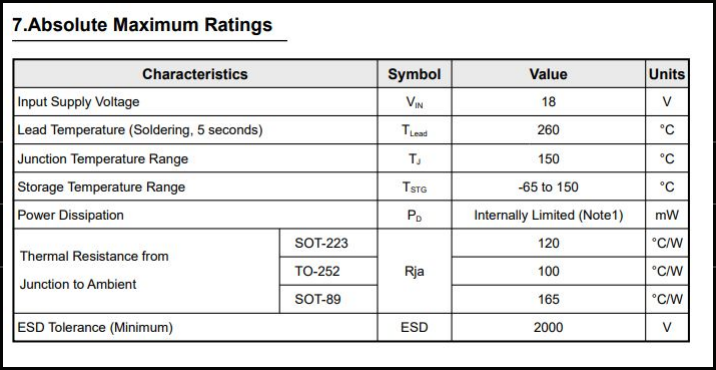
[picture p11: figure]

# UMW AMS1117-3.3

# Esquemáticos

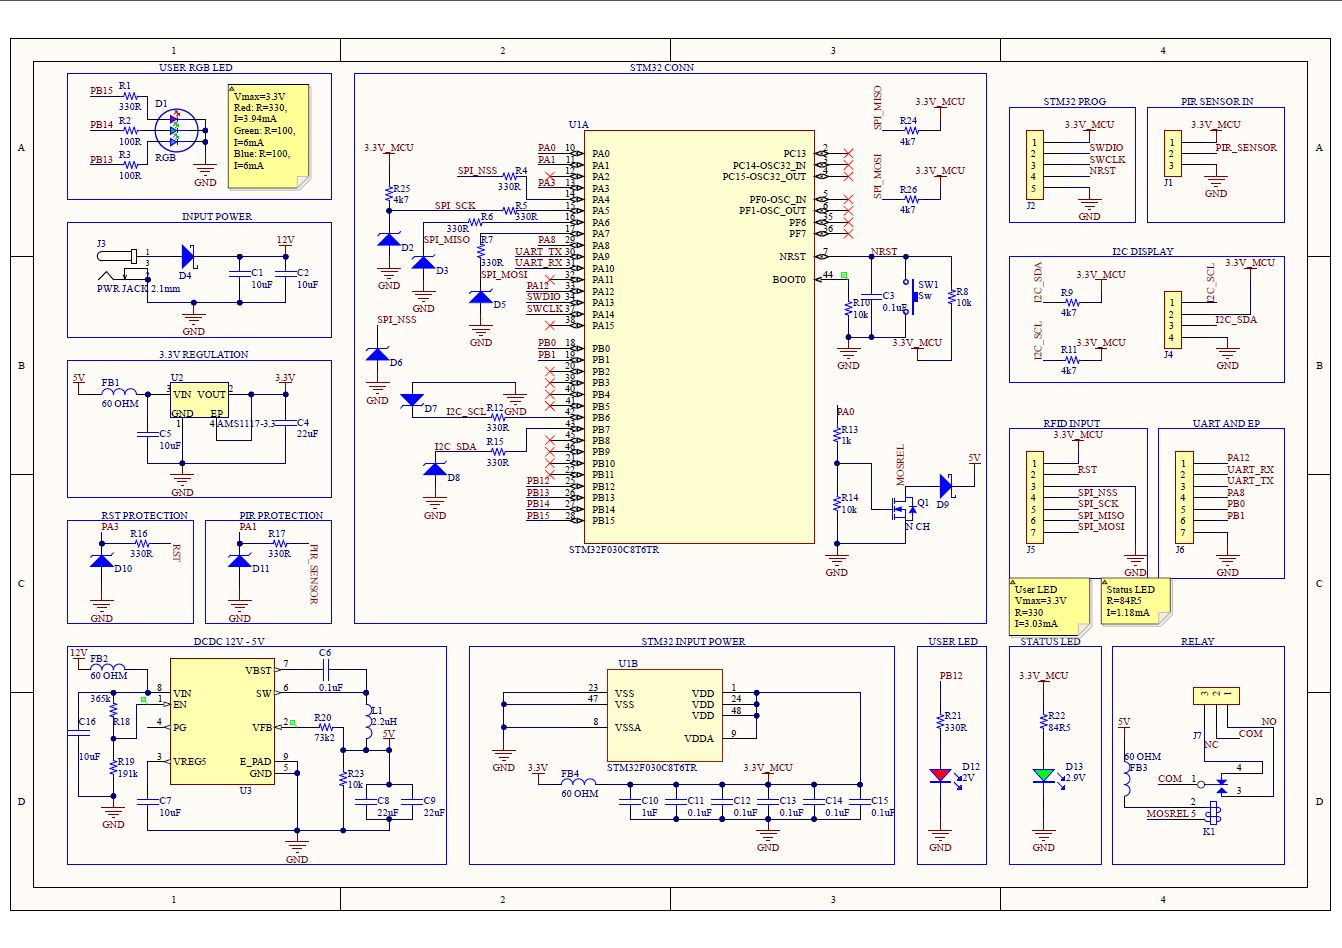
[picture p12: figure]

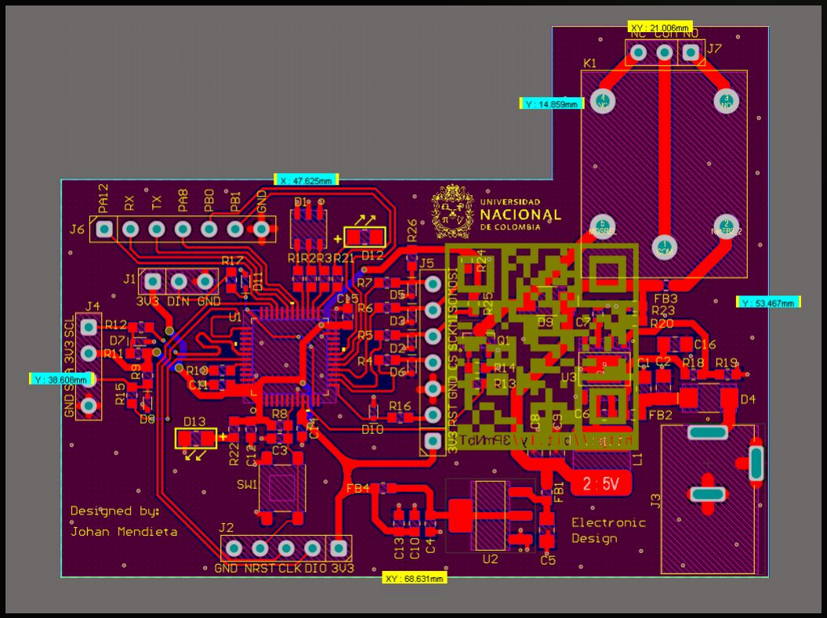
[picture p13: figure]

Protección ESD: Diodos de clamping en líneas de datos para evitar transitorios.

Filtrado EMI: Ferrite Beads (60 Ohm) en todas las líneas de alimentación críticas.

Desacople: Redes de capacitores de 0.1uF situadas físicamente cerca de cada pin VDD del MCU.

# Decisiones de Diseño Esquemático

# Decisiones de Diseño Esquemático

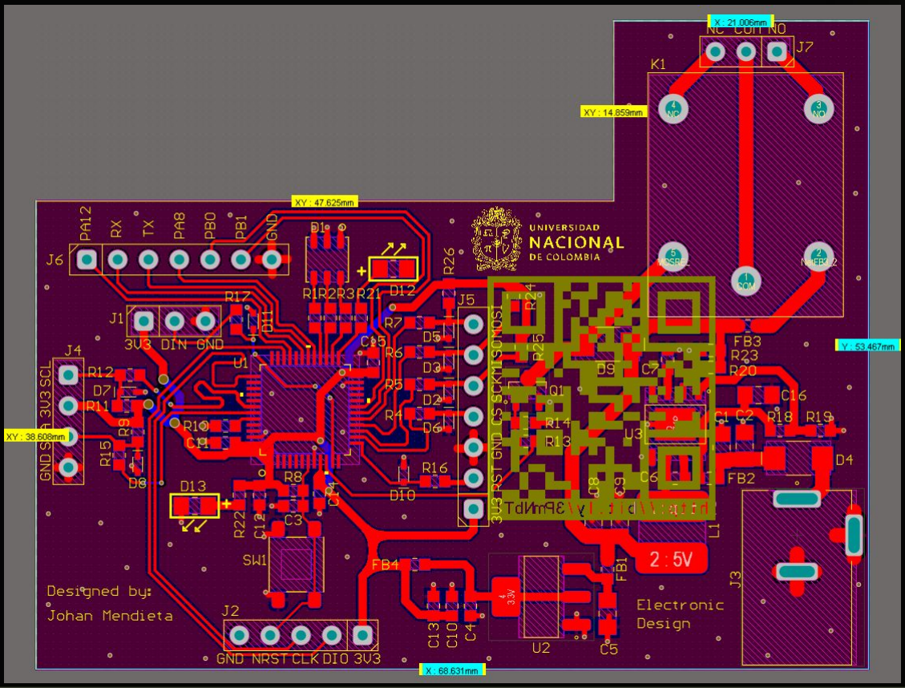
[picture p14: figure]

# Decisiones de Diseño Esquemático

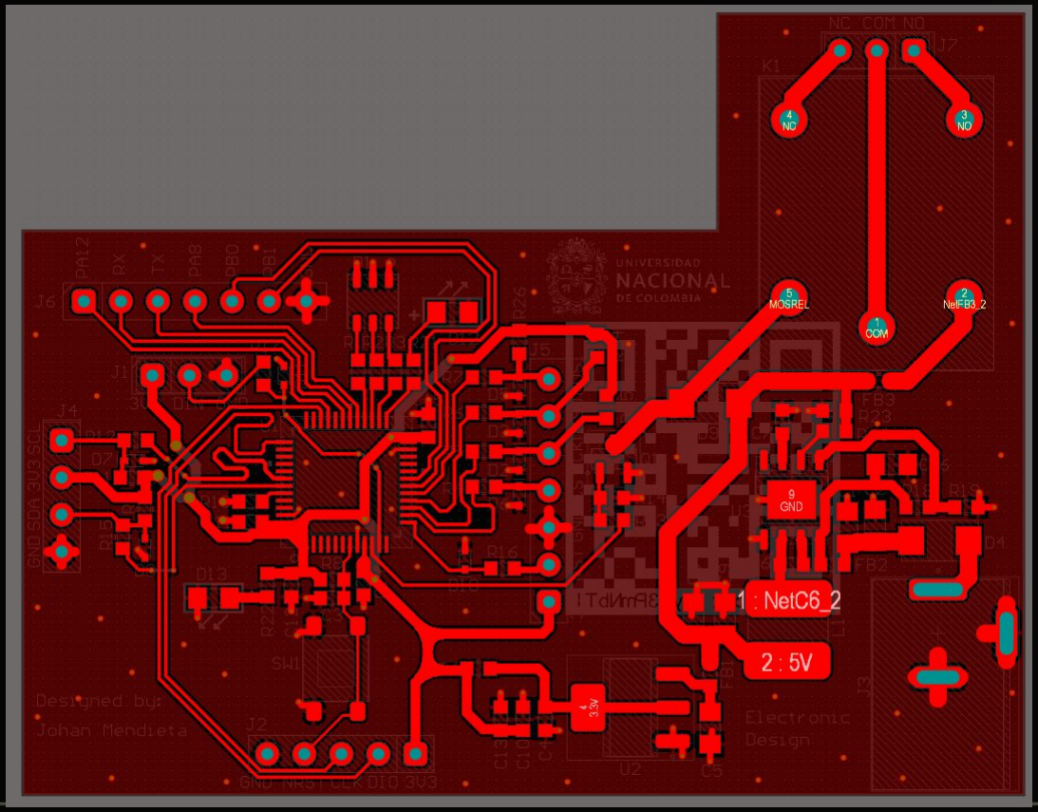
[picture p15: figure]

# Decisiones de Diseño Esquemático

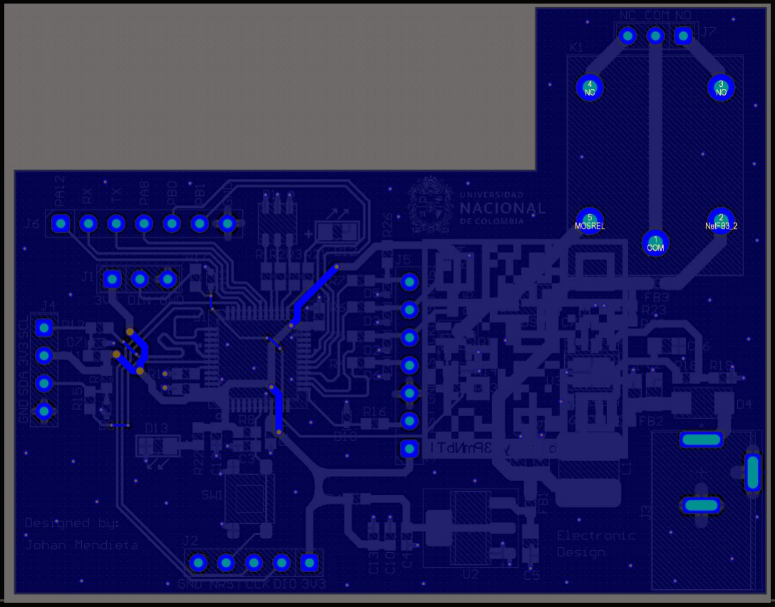
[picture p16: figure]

# PCB 3D

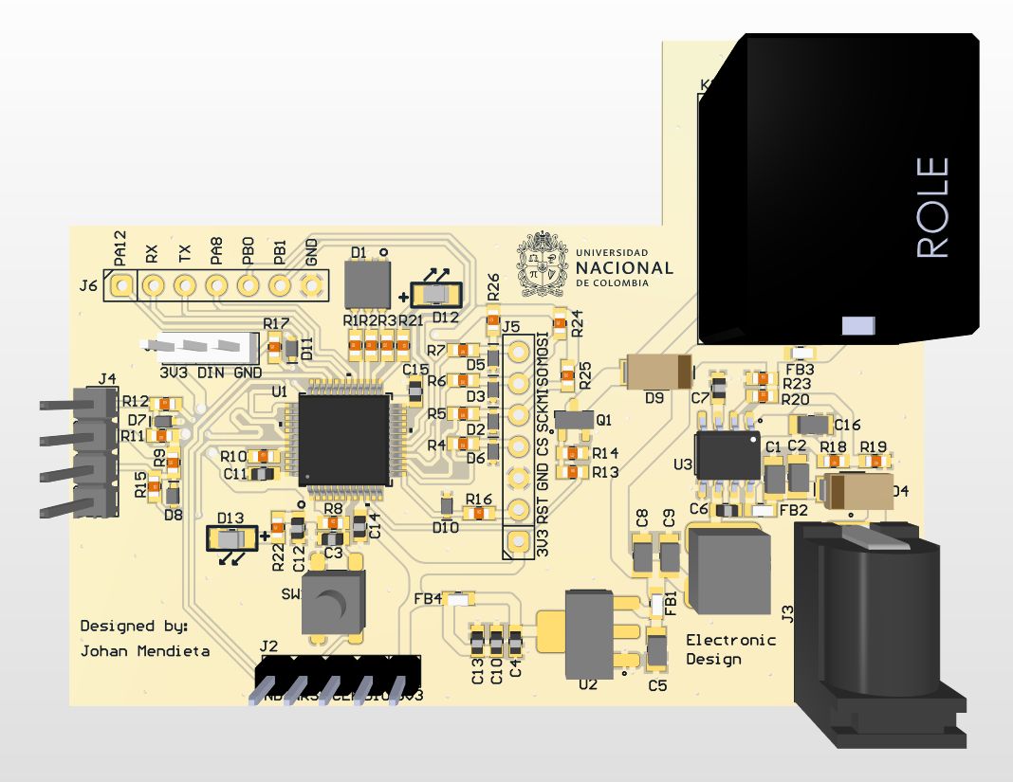
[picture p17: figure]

# PCB 3D

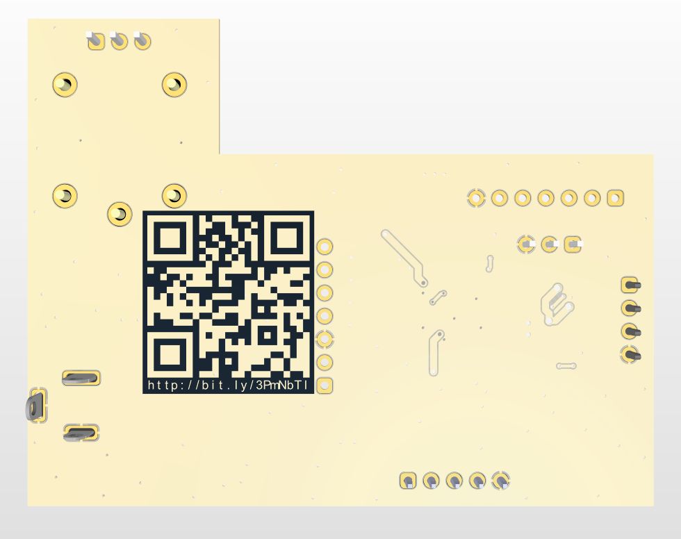
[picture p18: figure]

# Repositorio y Referencias

## Encuentre el código fuente, esquemáticos y documentación completa en:

Hojas de Datos | Contacto
| Johan S. Mendieta D.
| jomendietad@unal.edu.co
| Universidad Nacional de Colombia
- STM32F030C8T6 - STMicroelectronics
- ESP32-S3 Series - Espressif Systems
- TPS56528 Buck - Texas Instruments
- RC522 RFID Module - NXP Semi https://github.com/jomendietad/access-control-stm32-esp32

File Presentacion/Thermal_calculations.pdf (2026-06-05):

## Análisis Térmico de Componentes - Arbol de ´

## Potencia

5 de junio de 2026

## 1. Introducción y Metodología

El cálculo de la temperatura de unión (TJ ) de cada componente en estado estacionario se determina mediante la resistencia térmica desde la unión hacia el ambiente ambiente (RθJA), la potencia disipada (PD) y la temperatura ambiente (TA), que para este estudio se establece en 25 ◦C. La ecuación fundamental es:

TJ = TA + (PD × RθJA) | (1)

## 2. Cálculos por Componente

### 2.1. Convertidor Buck: TI TPS56528DDAR

Condiciones: Vin = 12V, Vout = 5V, Iout = 200mA (∼ 0,2A).

Potencia Disipada (PD): Asumiendo una eficiencia conservadora del η = 85 % en bajas corrientes. Pin =

Pout
η =

5V×0,2A
0,85 = 1,176W PD = Pin − Pout = 1,176W − 1,0W = 0,176W

Resistencia Térmica (RθJA): ∼ 45 ◦C/W (Empaque HSOIC-8 / DDA).

Temperatura (TJ ):
TJ = 25 + (0,176 × 45) = 32,92 ◦C

### 2.2. Regulador Lineal (LDO): AMS1117-3.3

Condiciones: Vin = 5V, Vout = 3,3V, Iout = 126mA (∼ 0,126A).

Potencia Disipada (PD): PD = (Vin −Vout)×Iout PD = (5−3,3)×0,126 = 1,7×0,126 = 0,214W

Resistencia Térmica (RθJA): ∼ 120 ◦C/W (Empaque SOT-223 en FR4 estándar).

Temperatura (TJ ):
TJ = 25 + (0,214 × 120) = 50,68 ◦C

### 2.3. MOSFET del Relé: DN2302S

Condiciones: Ids = 75mA (∼ 0,075A), RDS(on) ≈ 85mΩ (con Vgs = 3,3V).

Potencia Disipada (PD): PD = I

2

ds × RDS(on) PD = (0,075)² × 0,085 = 0,0056 × 0,085 = 0,000 47W

Resistencia Térmica (RθJA): ∼ 100 ◦C/W (Empaque SOT-23).

Temperatura (TJ ):
TJ = 25 + (0,00047 × 100) ≈ 25,04 ◦C

1

### 2.4. Microcontrolador: STM32F030C8T6

Condiciones: Vdd = 3,3V, Consumo estimado con periféricos I ≈ 40mA (∼ 0,04A).

Potencia Disipada (PD): PD = V × I = 3,3 × 0,04 = 0,132W

Resistencia Térmica (RθJA): ∼ 55 ◦C/W (Empaque LQFP-48).

Temperatura (TJ ):
TJ = 25 + (0,132 × 55) = 32,26 ◦C

## 3. Resumen y Conclusiones

Como se observa en el Cuadro 1, todos los componentes operan muy por debajo de sus límites térmicos máximos (típicamente 125◦C a 150◦C). El AMS1117-3.3 es el componente más cálido con 44,26◦C, pero se encuentra en una zona de operación completamente segura.

Cuadro 1: Resumen de Temperaturas Calculadas (TA = 25◦C)

Componente | Función | PD [W] RθJA [

◦C/W] TJ [

◦C]

TPS56528DDAR | Buck DC-DC | 0.176 | 45 | 32.92
AMS1117-3.3 | Regulador LDO | 0.214 | 120 | 50.68
DN2302S | Driver Relé | 0.00047 | 100 | 25.04
STM32F030C8 | MCU principal | 0.132 | 55 | 32.26

2

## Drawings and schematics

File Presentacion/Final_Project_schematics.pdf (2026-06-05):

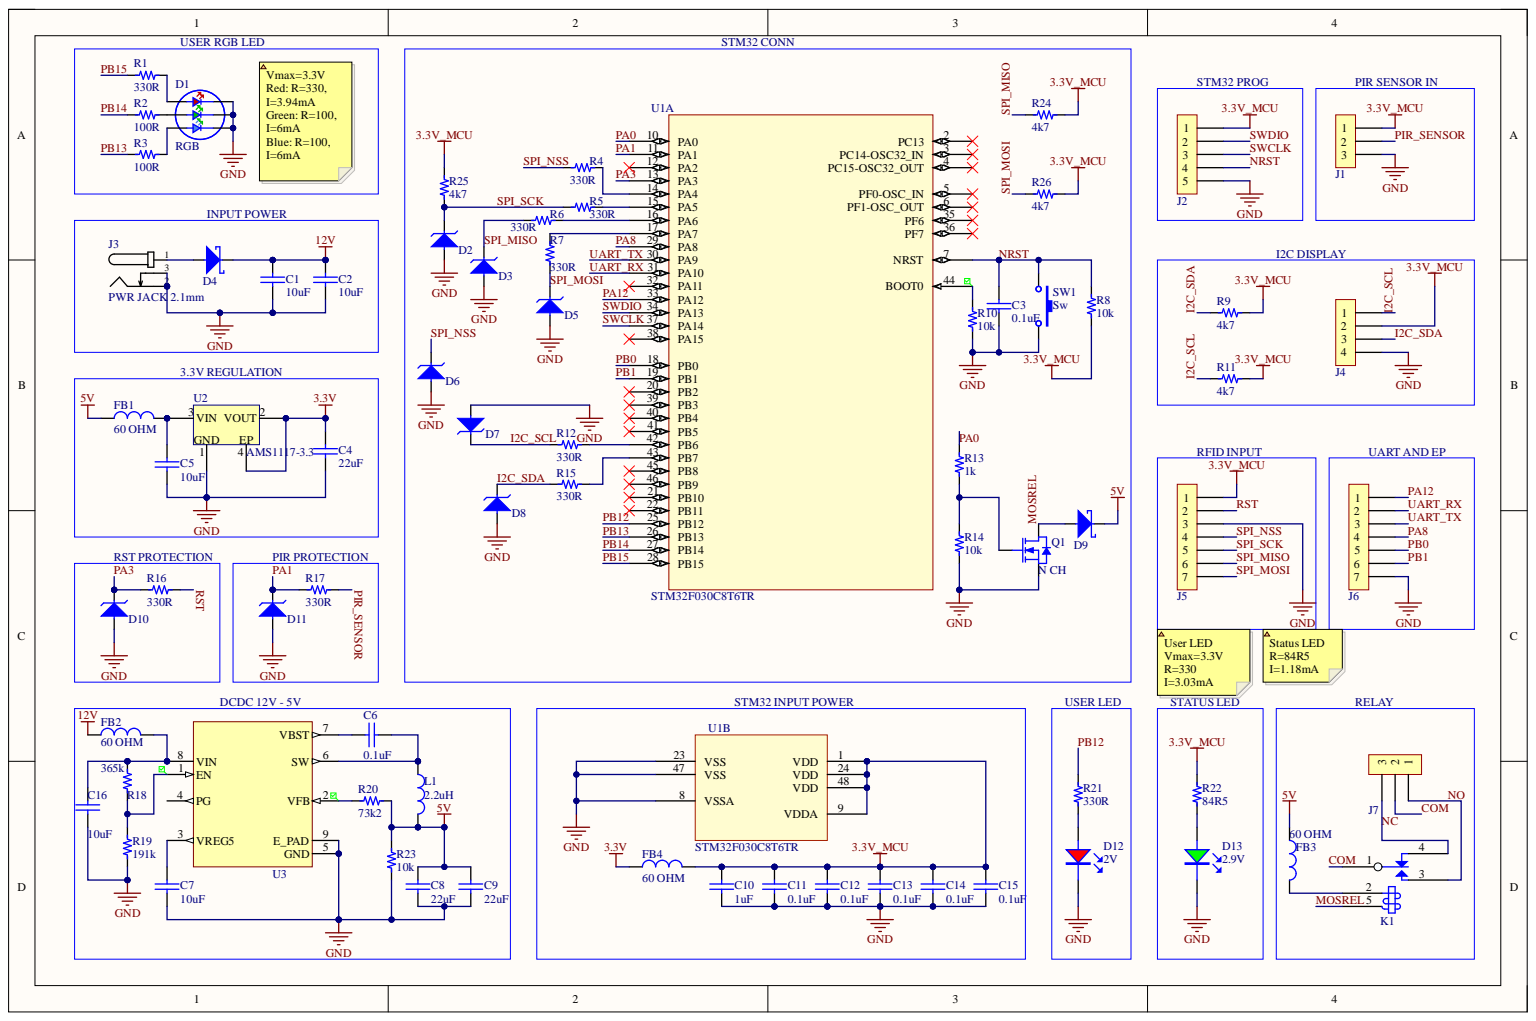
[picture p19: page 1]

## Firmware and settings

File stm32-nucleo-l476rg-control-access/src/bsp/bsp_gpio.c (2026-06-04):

#include "bsp/bsp_placa.h"
#include "bsp/bsp_gpio.h"

#define PIR_PIN    GPIO_PIN_0
#define PIR_PORT   GPIOA
#define RELAY_PIN  GPIO_PIN_1
#define RELAY_PORT GPIOA

void BSP_GPIO_Init(void) {
    __HAL_RCC_GPIOA_CLK_ENABLE();
    GPIO_InitTypeDef GPIO_InitStruct = {0};

    /* PIR Sensor Input */
    GPIO_InitStruct.Pin = PIR_PIN;
    GPIO_InitStruct.Mode = GPIO_MODE_INPUT;
    GPIO_InitStruct.Pull = GPIO_PULLDOWN;
    HAL_GPIO_Init(PIR_PORT, &GPIO_InitStruct);

    /* Relay Output */
    GPIO_InitStruct.Pin = RELAY_PIN;
    GPIO_InitStruct.Mode = GPIO_MODE_OUTPUT_PP;
    GPIO_InitStruct.Pull = GPIO_NOPULL;
    GPIO_InitStruct.Speed = GPIO_SPEED_FREQ_LOW;
    HAL_GPIO_Init(RELAY_PORT, &GPIO_InitStruct);
    
    HAL_GPIO_WritePin(RELAY_PORT, RELAY_PIN, GPIO_PIN_RESET);
}

bool BSP_GPIO_ReadPIR(void) {
    return (HAL_GPIO_ReadPin(PIR_PORT, PIR_PIN) == GPIO_PIN_SET);
}

void BSP_GPIO_SetRelay(bool state) {
    HAL_GPIO_WritePin(RELAY_PORT, RELAY_PIN, state ? GPIO_PIN_SET : GPIO_PIN_RESET);
}

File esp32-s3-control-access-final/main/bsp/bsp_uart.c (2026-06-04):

#include "bsp_uart.h"
#include "driver/uart.h"
#include "driver/gpio.h"
#include <string.h>

void BSP_UART_Init(void) {
    uart_config_t uart_config = {
        .baud_rate = UART_BAUD_RATE,
        .data_bits = UART_DATA_8_BITS,
        .parity    = UART_PARITY_DISABLE,
        .stop_bits = UART_STOP_BITS_1,
        .flow_ctrl = UART_HW_FLOWCTRL_DISABLE,
        .source_clk = UART_SCLK_DEFAULT,
    };
    uart_param_config(UART_PORT_NUM, &uart_config);
    uart_set_pin(UART_PORT_NUM, UART_TX_PIN, UART_RX_PIN, UART_PIN_NO_CHANGE, UART_PIN_NO_CHANGE);
    uart_driver_install(UART_PORT_NUM, 256, 0, 0, NULL, 0);
}

void BSP_UART_SendResult(bool is_known) {
    const char* msg = is_known ? "K\n" : "U\n";
    uart_write_bytes(UART_PORT_NUM, msg, strlen(msg));
}

bool BSP_UART_ReadTest(char* rx_buffer, size_t max_len) {
    // Wait up to 100ms for the loopback data to arrive
    int len = uart_read_bytes(UART_PORT_NUM, rx_buffer, max_len - 1, pdMS_TO_TICKS(100));
    if (len > 0) {
        rx_buffer[len] = '\0';
        return true;
    }
    return false;
}
